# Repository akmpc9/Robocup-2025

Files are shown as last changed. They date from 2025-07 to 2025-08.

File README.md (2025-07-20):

# Robocup-2025

## What is Robocup?
[Robocup Junior Soccer Open](https://junior.robocup.org/soccer/) is a league of the international robotic competition: [RoboCup](https://robocup.org).
For this competition, we need to create _two fully autonomous robots_ that play _soccer_ against other teams. We have to design, build and program the robots without external help. This is a really challenging problem because the robots need to be fully autonomous. They need to detect the ball and try to go towards it to hopefully push it towards the goal. A camera system is needed to try to detect the ball based on its color (it's an orange golf ball) and to detect the opponent's goal.

[Learn more about the competition](https://robocup-junior.github.io/soccer-rules/master/rules.html)

## The robots

## The team
We're a team of 3 high school students from Bordeaux.

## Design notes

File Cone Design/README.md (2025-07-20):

# The cone:
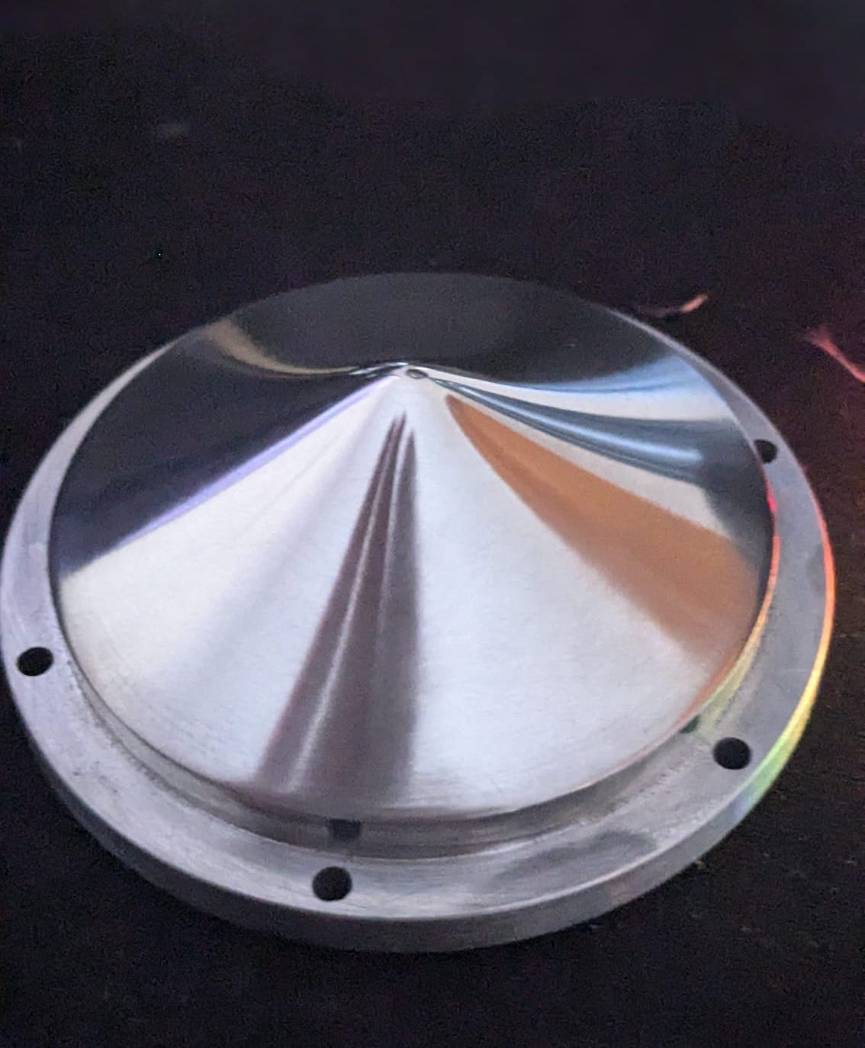
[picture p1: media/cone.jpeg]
Our cone


## What's the cone for?

Robots need to find the ball with the help of a camera. Many robots that simply place cameras in front of their robots need to make them spin until the ball enters the camera's field of vision, and can go towards it. This is a slow strategy. Instead of having the camera placed like this and having to spin slowly, many teams have found alternatives. The main alternatives are:
1. A camera with a fish-eye lens pointing down on the field.
2. Many cameras distributed around the robot.
3. A camera pointed up at a reflective cone.

Most teams go for the third option and so did we. A camera is pointing straight up from the center of the robot. A reflective cone (often cnc machined or created with a reflective film) is placed above it and lets the camera see an image of the field in the reflection. This lets the camera see in 360°.
We had an openmv h7 cam pointed at a cnc-machined aluminum cone.

The camera's view of the field through the cone
*This is the view on the field that the camera gets through our cone. When the cone and camera are well aligned, the cone truly creates a rectangular view of the field.

## Why our cone is interesting
Many teams use hyperbolic mirors to have a view of the field. The cross section of the cone is hyperbolic. We decided to try something different. In the camera's view, using a hyperbolic mirror, the field is very distorted. Seeing this issue, we created a program that creates the perfect cone shape (cross section) for the view of the field to be a rectangle in the image given many inputs such as the camera's position, the cone's position and the field of view. The camera returns an image of the field similar to a photo being taken from far above the field. The value of such an image is that the distance between two points that 15 pixels on the image represents is equivalent to those same 15 pixels somewhere else in the image. We can measure distances in pixels between objects straight off the image, multiply it by a constant and get centimeters. This let us rely solely on the camera to go towards the ball, go towards the goal and avoid going out of bounds.

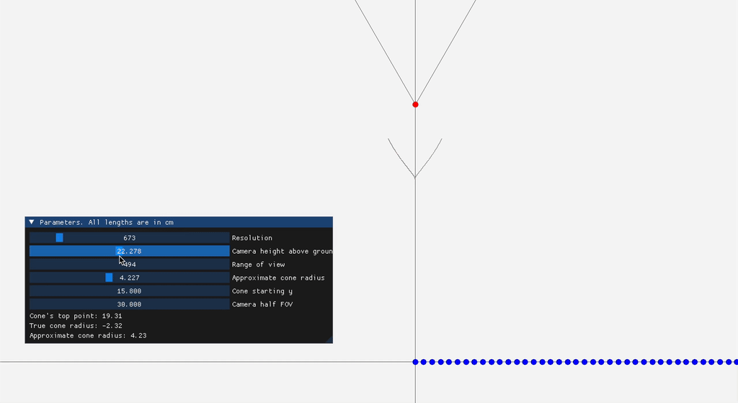
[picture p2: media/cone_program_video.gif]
Cone designing program

*The program has a GUI to let the user create the perfect cone shape based on the parameters. The red point is the camera. the whole image is a cross section of the field. the weirdly shaped line above the camera is the cross section of the cone. It outputs the stl file of the wanted cone when the program shuts.*

## What we would change for the 2026 competition
For next year, we will change many things around the cone:
1. The weight / size. The cone was rather large (6cm in diameter) and therefor raised the center of gravity (making strong accelerations lift a wheel off the ground. This is very negative as it means we lose some control over the robot's movement, and the vision system also breaks down due to measured distances not being valid at all when the robot isn't flat on the ground). Next year, we will create much smaller cones to avoid these issues and to reduce the price of the raw materials.
2. Although the program gave us the shape of the cone we wanted based on our inputted values, it turned out that a range of 1.5m isn't quite enough for the robot (we couldn't see the opponent's goal when we were in our half of the field for example). In other words, the system that gave us the cone worked well, but the values that we gave it will be changed for next year. Another solution to the issue of not seeing the opponent's goal is simply using a lidar (which is the plan for next year's robots) to know exactly where the robot is on the field with the camera only inputting which goal is the closest rather than finding the opponent's goal position.

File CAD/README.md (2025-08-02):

# CAD Models

[Click here to view the full model in Onshape](https://cad.onshape.com/documents/38b8aa48dace08227087a0ba/w/a7972c026289a2e11ccdfcb7/e/f6010eaa08c50660caaa18c2)

---

## 📸 Previews

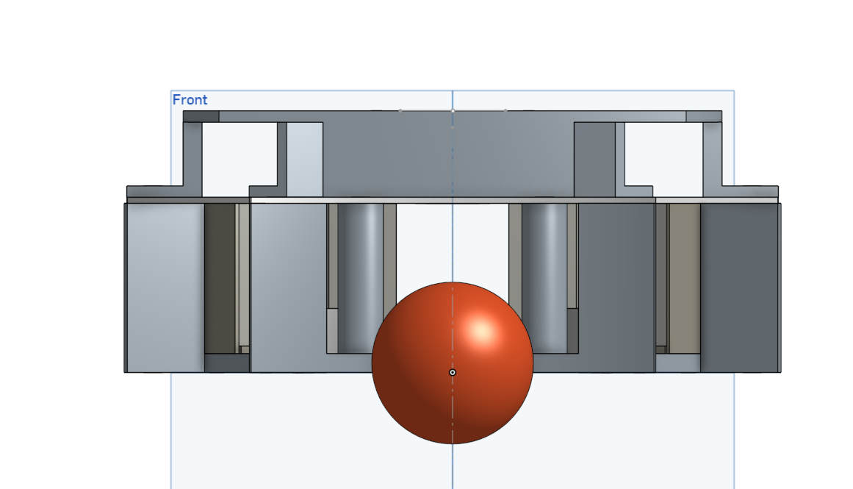
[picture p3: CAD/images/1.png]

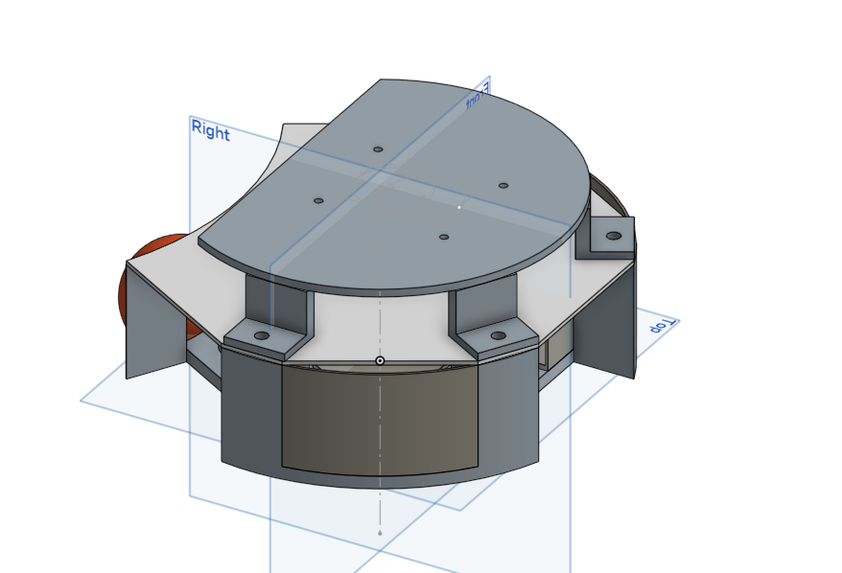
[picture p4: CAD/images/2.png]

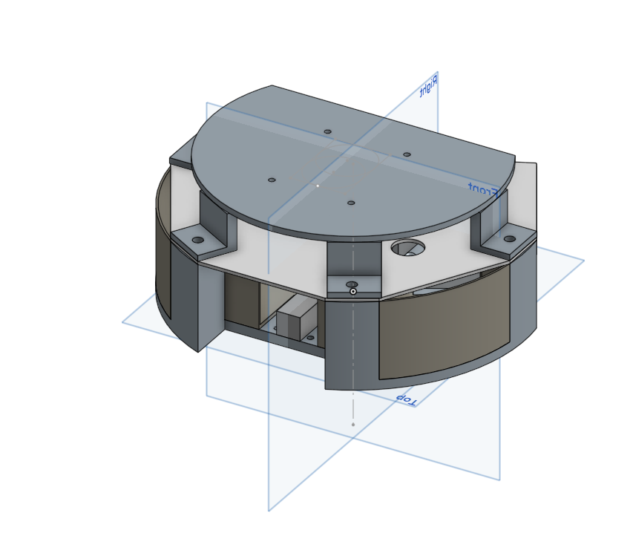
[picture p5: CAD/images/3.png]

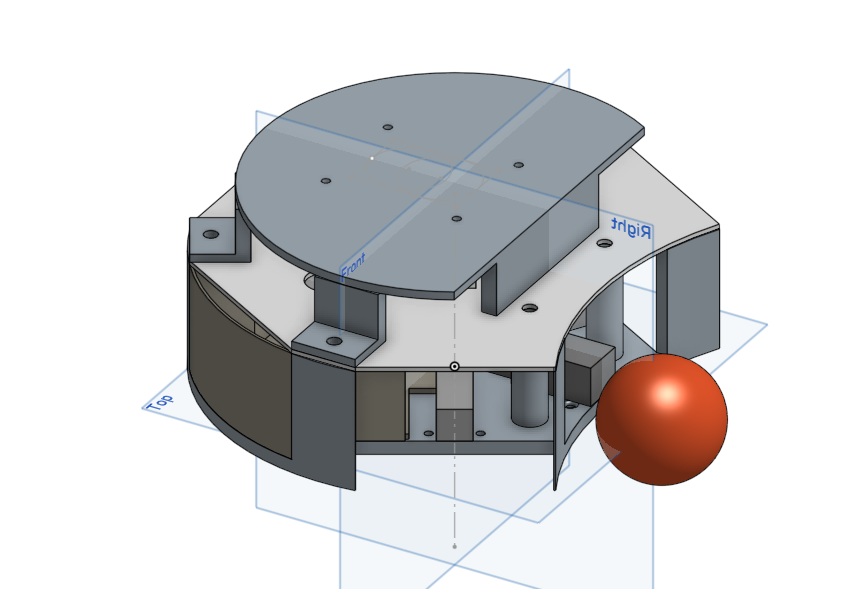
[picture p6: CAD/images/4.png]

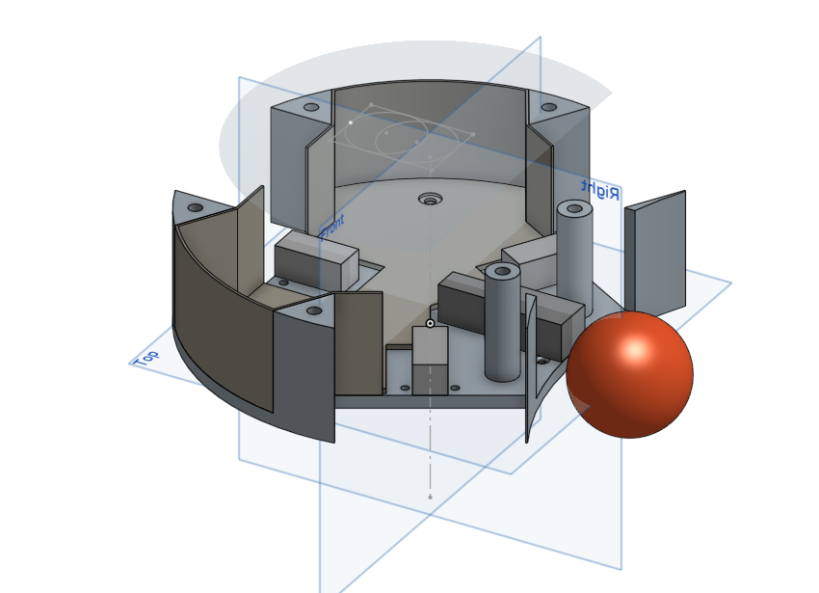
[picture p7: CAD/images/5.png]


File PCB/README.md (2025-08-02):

# Custom PCB Design

This is a 2-layer custom PCB designed in **KiCad 9** and manufactured via **JLCPCB**.

---

## About
  
the **PCB** was created using **KiCad 9**, with a focus on simplicity, and ease of assembly.

---

## Specs

-  **Layers**: 2
-  **EDA Tool**: KiCad 9
-  **Manufacturer**: JLCPCB
-  **Board Dimensions**: _[175mm x 175mm]_
-  **Ground pour for thermal management and EMI reduction.**

---

## 📁 Design Files

The following files are included in this repo:

- `*.kicad_pro` – KiCad 9 project file  
- `*.kicad_pcb` – PCB layout  
- `*.sch` – Schematic  
- `*.pdf` – Schematic2  

---

##  Manufacturing

These files were exported for and tested with **JLCPCB**.

- Designed using [KiCad](https://kicad.org/)
- Manufactured by [JLCPCB](https://jlcpcb.com)

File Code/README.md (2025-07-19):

The Code on our robots worked with two separate components: the esp32 and the camera. The esp32 controlled the robot's movements through the motor controllers while the camera, being the only sensor on board, made of all the stategic decisions. The esp32 was slave to the camera and just recieved simple instructions to move, which it then translated into the individual motor speeds and sent the right instructions to the motor controllers.

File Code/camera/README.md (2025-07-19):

As is rather common with robotics competitions and larger projects, code and other pieces of data aren't often well archived on the spurr of the moment. During competitions, we are often concentrated on getting a version of the code that's working with the current situations rather than saving which versions we used. We therefor can't show one program that represents our robots' code. Many versions have been changed numerous times, and code often changed from one match to the next. In any case, this is the code that has the main components of the code that gave us a goal in six seconds.

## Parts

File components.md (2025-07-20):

# The following are the comoponents we used on the robots for the 2025 competitions
These are the components _per robot_
<span style="color: #FF0000;">This text is red</span>

- Motor controllers:
   - TB6612FNG Motor Driver x2
- Motors:
   - Motoréducteur HPCB 3039, 50:1 (n20 motors) x3
- Wheels:
   - 60mm Omni Wheel Set Plastic x3
- Camera:
   - OpenMV h7 cam x1
- Microcontroller:
   - Esp32 x1
- Materials:
   - PLA for 3d printed parts
   - Aluminum for the cnc machined cone

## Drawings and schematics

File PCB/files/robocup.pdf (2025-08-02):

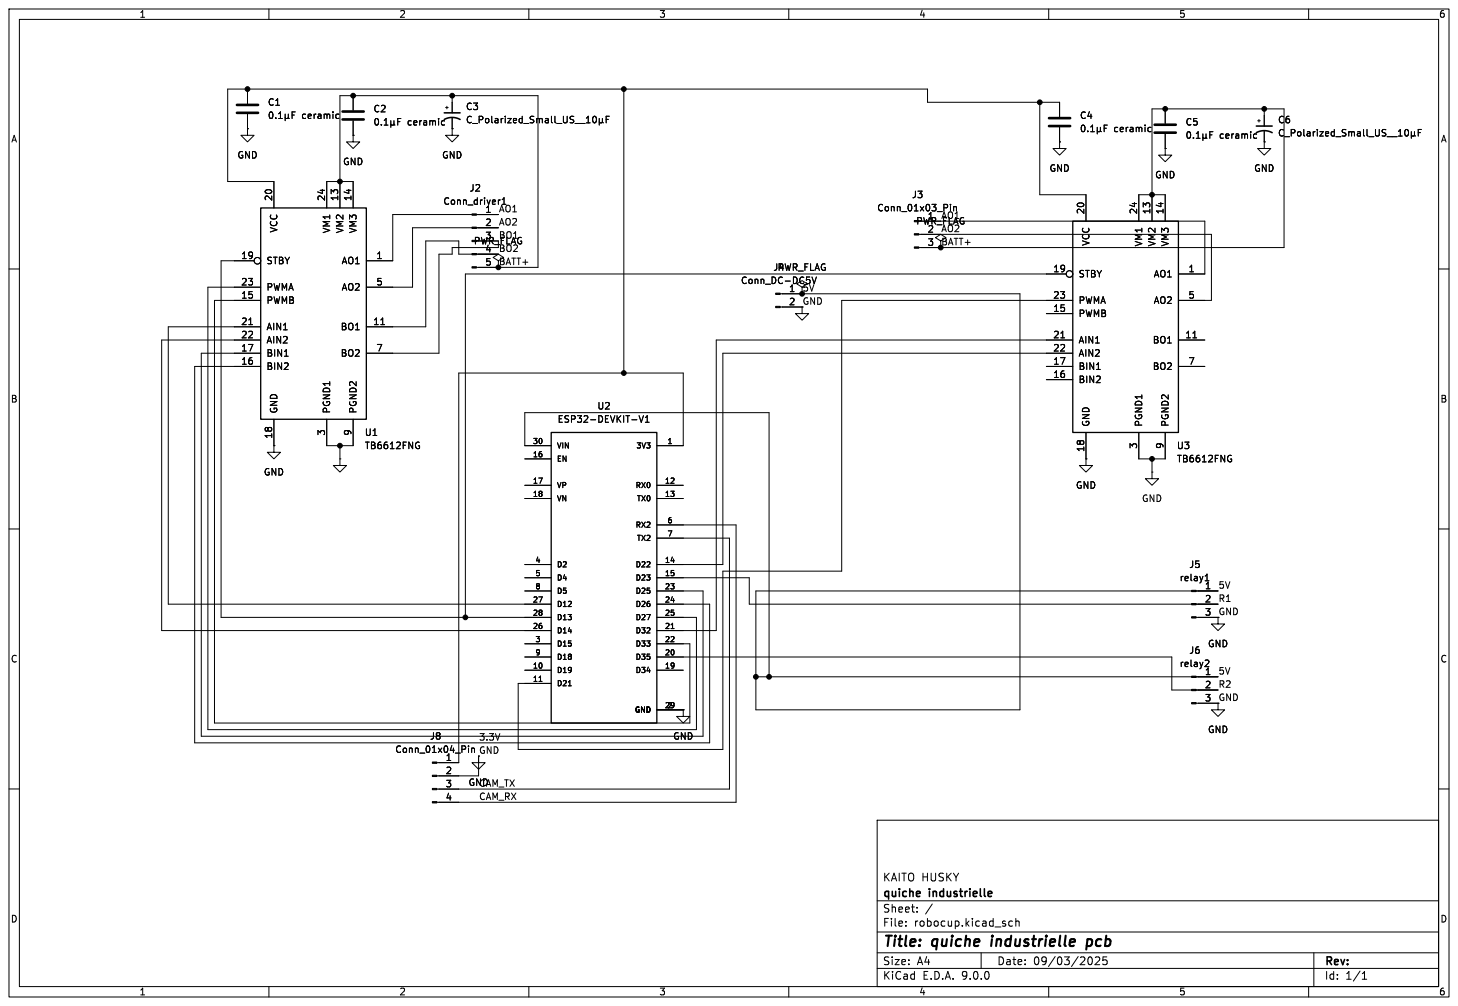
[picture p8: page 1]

File: robocup.kicad_sch Sheet: / quiche industrielle KAITO HUSKY

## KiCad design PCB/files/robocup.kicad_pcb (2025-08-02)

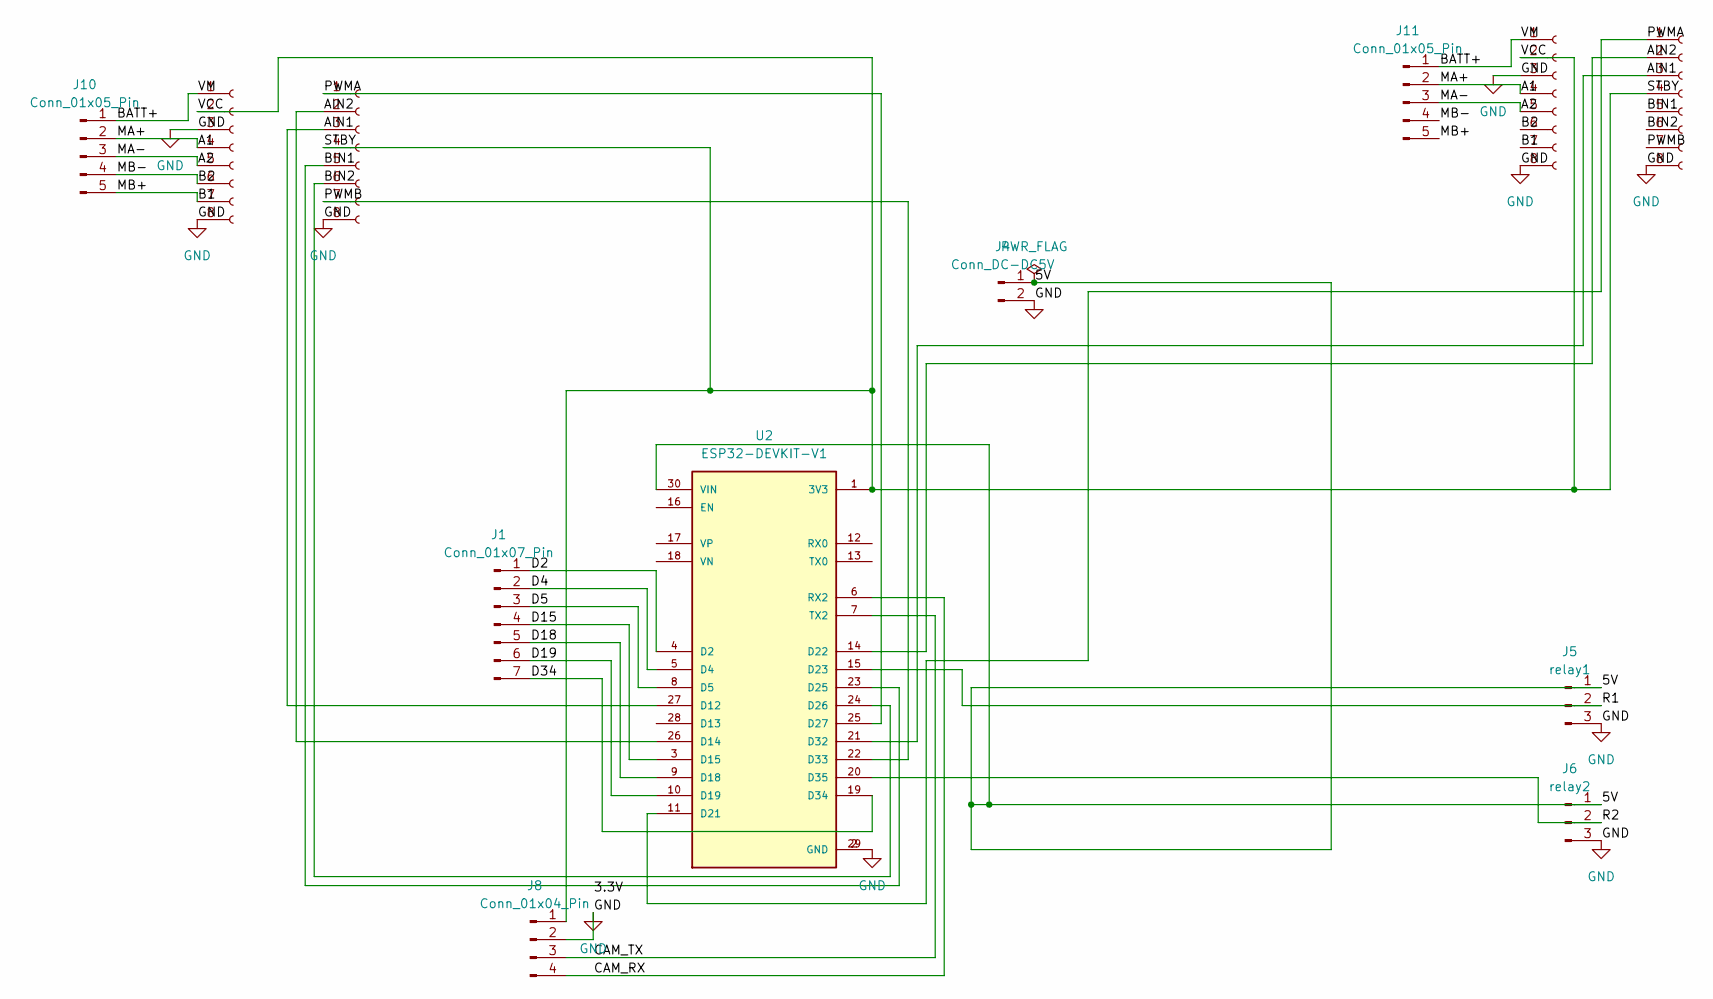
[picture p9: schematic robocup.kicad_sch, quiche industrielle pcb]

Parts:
J1: Conn_01x07_Pin; PinHeader_1x07_P2.54mm_Vertical
J2, J3, J7, J9: Conn_01x08_Socket; PinSocket_1x08_P2.54mm_Vertical
J4: Conn_DC-DC5V; PinHeader_1x02_P2.54mm_Vertical
J5: relay1; PinHeader_1x03_P2.54mm_Vertical
J6: relay2; PinHeader_1x03_P2.54mm_Vertical
J8: Conn_01x04_Pin; PinHeader_1x04_P2.54mm_Vertical
J10, J11: Conn_01x05_Pin; PinHeader_1x05_P2.54mm_Vertical
U2: ESP32-DEVKIT-V1; MODULE_ESP32_DEVKIT_V1; PARTREV N/A

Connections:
/5V: J4.1, J5.1, J6.1, U2.30 (VIN)
/A1: J2.4, J7.4, J10.2, J11.2
/A2: J2.5, J7.5, J10.3, J11.3
/AIN1: J3.3, J9.3, U2.21 (D32), U2.27 (D12)
/AIN2: J3.2, J9.2, U2.14 (D22), U2.26 (D14)
/B1: J2.7, J7.7, J10.5, J11.5
/B2: J2.6, J7.6, J10.4, J11.4
/BATT+: J2.1, J7.1, J10.1, J11.1
/BIN1: J3.5, J9.5, U2.23 (D25)
/BIN2: J3.6, J9.6, U2.24 (D26)
/CAM_RX: J8.4, U2.6 (RX2)
/CAM_TX: J8.3, U2.7 (TX2)
/D2: J1.1, U2.4 (D2)
/D4: J1.2, U2.5 (D4)
/D5: J1.3, U2.8 (D5)
/D15: J1.4, U2.3 (D15)
/D18: J1.5, U2.9 (D18)
/D19: J1.6, U2.10 (D19)
/D34: J1.7, U2.19 (D34)
/PWMA: J3.1, J9.1, U2.11 (D21), U2.25 (D27)
/PWMB: J3.7, J9.7, U2.22 (D33)
/R1: J5.2, U2.15 (D23)
/R2: J6.2, U2.20 (D35)
/STBY: J2.2, J3.4, J7.2, J8.1, J9.4, U2.1 (3V3)
GND: J2.3, J2.8, J3.8, J4.2, J5.3, J6.3, J7.3, J7.8, J8.2, J9.8, U2.2 (GND), U2.29 (GND)

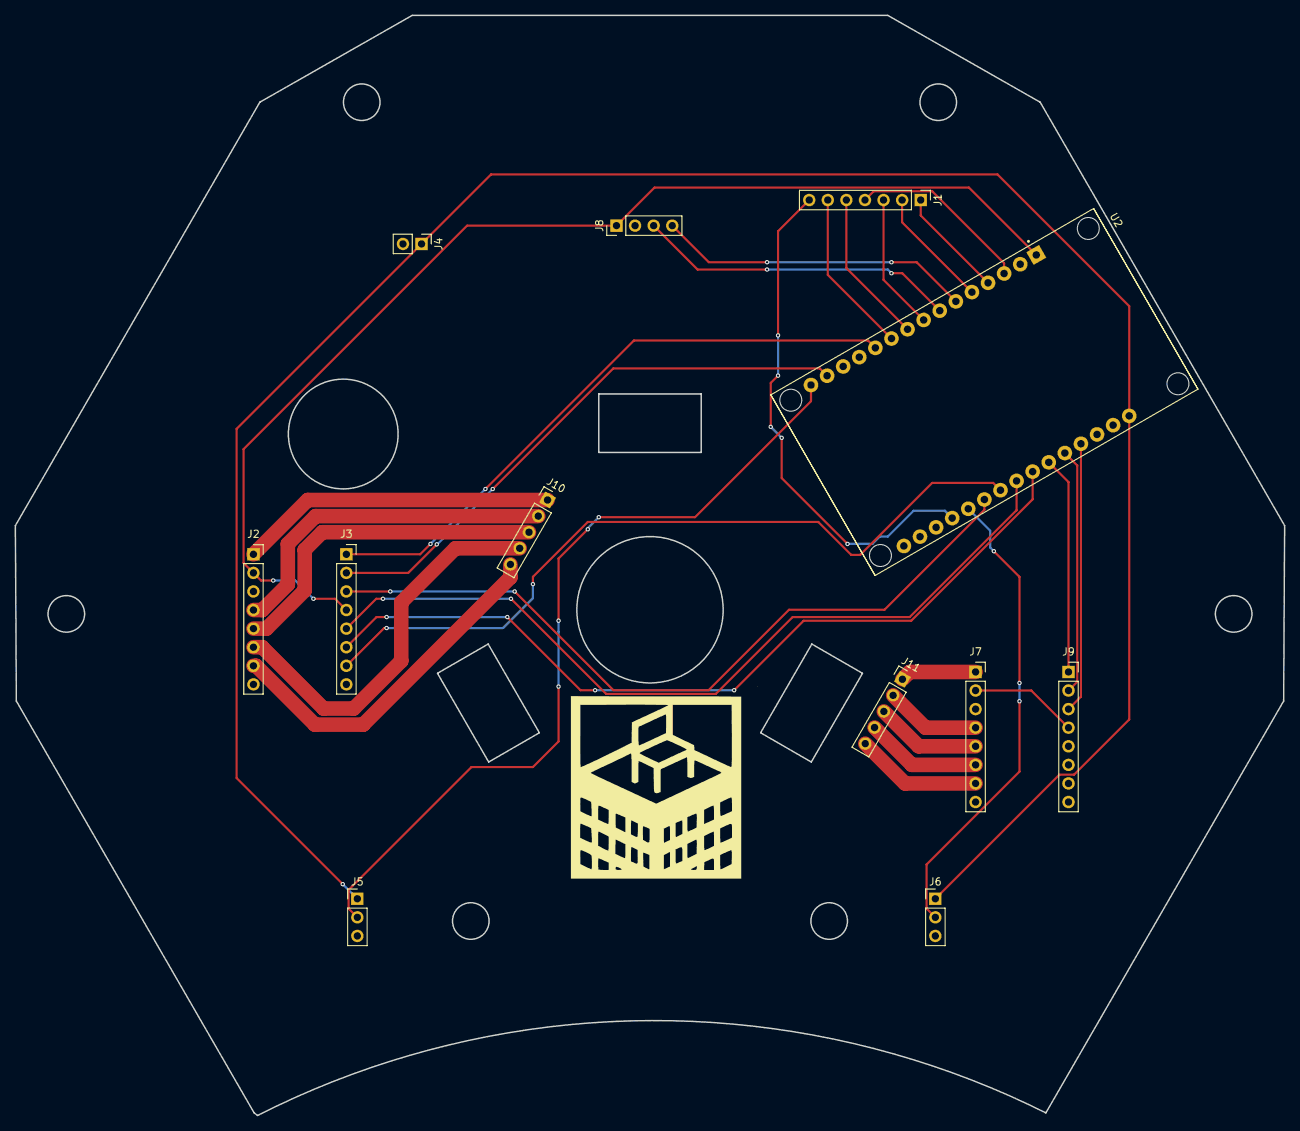
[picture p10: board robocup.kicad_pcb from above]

Board: 2 copper layers, 173.5 x 150.4 mm, 12 parts (0 on the bottom side), 25 nets.

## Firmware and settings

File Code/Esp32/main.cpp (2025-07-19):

#include "driver/mcpwm.h"
#include <HardwareSerial.h>

HardwareSerial camSerial(2);

int PWMB = 25;
int BIN1 = 27;
int BIN2 = 26;

int PWMC = 13;
int CIN1 = 14;
int CIN2 = 12;

int PWMA = 4;
int AIN1 = 15;
int AIN2 = 2;

const float motor_A[2] = {-0.5, 0.866025};
const float motor_B[2] = {-0.5, -0.866025};
const float motor_C[2] = {1, 0};

void setup() {
    Serial.begin(115200);
    mcpwm_gpio_init(MCPWM_UNIT_0, MCPWM0A, PWMA);
    mcpwm_gpio_init(MCPWM_UNIT_0, MCPWM0B, PWMB);
    mcpwm_gpio_init(MCPWM_UNIT_1, MCPWM0A, PWMC);

    mcpwm_config_t pwm_config = {
        .frequency = 5000,
        .cmpr_a = 0,
        .cmpr_b = 0,
        .duty_mode = MCPWM_DUTY_MODE_0,
        .counter_mode = MCPWM_UP_COUNTER
    };

    mcpwm_init(MCPWM_UNIT_0, MCPWM_TIMER_0, &pwm_config);
    mcpwm_init(MCPWM_UNIT_1, MCPWM_TIMER_0, &pwm_config);

    pinMode(AIN1, OUTPUT);
    pinMode(AIN2, OUTPUT);
    pinMode(BIN1, OUTPUT);
    pinMode(BIN2, OUTPUT);
    pinMode(CIN1, OUTPUT);
    pinMode(CIN2, OUTPUT);

    camSerial.begin(115200, SERIAL_8N1, 16, 17);
}

void setMotorA(float speed) {
    if (speed > 0) {
        digitalWrite(AIN1, HIGH);
        digitalWrite(AIN2, LOW);
    } else {
        digitalWrite(AIN1, LOW);
        digitalWrite(AIN2, HIGH);
        speed = -speed;
    }
    mcpwm_set_duty(MCPWM_UNIT_0, MCPWM_TIMER_0, MCPWM_OPR_A, speed);
}

void setMotorB(float speed) {
    if (speed > 0) {
        digitalWrite(BIN1, HIGH);
        digitalWrite(BIN2, LOW);
    } else {
        digitalWrite(BIN1, LOW);
        digitalWrite(BIN2, HIGH);
        speed = -speed;
    }
    mcpwm_set_duty(MCPWM_UNIT_0, MCPWM_TIMER_0, MCPWM_OPR_B, speed);
}

void setMotorC(float speed) {
    if (speed > 0) {
        digitalWrite(CIN1, HIGH);
        digitalWrite(CIN2, LOW);
    } else {
        digitalWrite(CIN1, LOW);
        digitalWrite(CIN2, HIGH);
        speed = -speed;
    }
    mcpwm_set_duty(MCPWM_UNIT_1, MCPWM_TIMER_0, MCPWM_OPR_A, speed);
}

void moveBy(float x, float y, float r = 0) {
    x *= 100;
    y *= -100;
    float powerA = x * motor_A[0] + y * motor_A[1] + r;
    float powerB = x * motor_B[0] + y * motor_B[1] + r;
    float powerC = x * motor_C[0] + y * motor_C[1] + r;
    setMotorA(powerA);
    setMotorB(powerB);
    setMotorC(powerC);
}

void rotateBy(float r) {
    setMotorA(r);
    setMotorB(r);
    setMotorC(r);
}

void loop() {
    if (camSerial.available() || Serial.available() > 0) {
        String cmd;

        if (Serial.available() > 0) {
            cmd = Serial.readStringUntil('\n');
        } else {
            cmd = camSerial.readStringUntil('\n');
        }

        char cmdType = cmd.charAt(0);
        float speed, r, x, y;
        int firstComma, secondComma;

        switch (cmdType) {
            case 'A':
            case 'B':
            case 'C':
                speed = cmd.substring(2).toFloat();
                if (cmdType == 'A') {
                    setMotorA(speed);
                    Serial.printf("set A to %.1f%%\n", speed);
                } else if (cmdType == 'B') {
                    setMotorB(speed);
                    Serial.printf("set B to %.1f%%\n", speed);
                } else {
                    setMotorC(speed);
                    Serial.printf("set C to %.1f%%\n", speed);
                }
                break;

            case 'V':
                firstComma = cmd.indexOf(',');
                secondComma = cmd.indexOf(',', firstComma + 1);
                if (secondComma > 0) {
                    x = cmd.substring(firstComma + 1, secondComma).toFloat();
                    int thirdComma = cmd.indexOf(',', secondComma + 1);
                    if (thirdComma > 0) {
                        y = cmd.substring(secondComma + 1, thirdComma).toFloat();
                        r = cmd.substring(thirdComma + 1).toFloat();
                        moveBy(x, y, r);
                        Serial.printf("moving: x=%.2f, y=%.2f, r=%.2f\n", x, y, r);
                    } else {
                        y = cmd.substring(secondComma + 1).toFloat();
                        moveBy(x, y);
                        Serial.printf("moving: x=%.2f, y=%.2f\n", x, y);
                    }
                }
                break;

            case 'R':
                r = cmd.substring(2).toFloat();
                rotateBy(r);
                Serial.printf("rotating: r=%.2f\n", r);
                break;

            case 'S':
                moveBy(0, 0);
                break;

            default:
                Serial.println("Unknown command");
                break;
        }
    }
}

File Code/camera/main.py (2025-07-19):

import sensor
import time
import math
from pyb import UART
import image


class Vector2:
    def __init__(self, x, y):
        self.x = x
        self.y = y
        self.mag = math.sqrt(self.x*self.x + self.y*self.y)
        if self.mag == 0:
            self.mag = 1

    def normalize(self):
        if self.mag == 0:
            return Vector2(0, 0)
        return Vector2(self.x/self.mag, self.y/self.mag)

    def scale(self, factor):
        return Vector2(self.x*factor, self.y*factor)

    def as_tuple(self):
        return (int(self.x), int(self.y))

    def __add__(self, other):
        return Vector2(self.x + other.x, self.y + other.y)

    def __sub__(self, other):
        return Vector2(self.x - other.x, self.y - other.y)

    def __mul__(self, other):
        return Vector2(self.x * other, self.y * other)

    def __truediv__(self, other):
        return Vector2(self.x / other, self.y / other)

    def __repr__(self):
        return f"Vector2({self.x}, {self.y})"

    def get_angle_degrees(self):
        if self.x == 0 and self.y == 0:
            return 0

        angle = math.atan2(-self.y, -self.x)

        angle_degrees = angle * 180 / math.pi

        return angle_degrees

    def rotate(self, degrees):
        radians = math.radians(degrees)

        old_x = self.x
        old_y = self.y

        new_x = old_x * math.cos(radians) - old_y * math.sin(radians)
        new_y = old_x * math.sin(radians) + old_y * math.cos(radians)

        return Vector2(new_x, new_y)


class Strategy:
    def __init__(self):
        self.state = "search"
        self.last_rotation = None
        # track rotation changes
        self.rotation_history = []
        self.frames_no_ball = 0
        self.frame = 0

    def update(self):
        # ball = get_ball()
        # diff = Vector2(0, 0)
        # if ball:
        #     diff = Vector2(ball.cx(), ball.cy()) - center
        #
        # angle = 0
        # goal = get_color_blob((0, 32, 5, 77, -47, -10))
        # if goal:
        #     angle = goal.cx() - center.x
        #
        # uart.write(f"V,{-diff.x / 100},0,{angle / 10}\n")
        # uart.write("R,40\n")
        # if self.state == "search":
        self.search()
        # elif self.state == "attack":
        # self.attack()
        # elif self.state == "recenter":
        #     self.recenter()
        # else:
        #     uart.write("S\n")

    def stay_in_bounds(self):
        movement = Vector2(0, 0)
        optimal_distance = 33
        for i in range(0, 360, 45):
            diff = raycaster(Vector2(-1, 0).rotate(i), field_threshold)

            if diff.mag < optimal_distance:
                img.draw_circle(*(center + diff).as_tuple(), 3, (255, 0, 0))
                movement += diff * (-diff.mag / (optimal_distance * 60))

        return movement

    def recenter(self):
        East = raycaster(Vector2(0, 1), field_threshold)
        West = raycaster(Vector2(0, -1), field_threshold)

        ball = get_ball()
        if ball:
            self.state = "search"

        angle = 0
        d_y = 164

        if abs(East.mag - West.mag) < 30:
            goal = get_goal()
            if goal:
                diff = Vector2(goal.cx(), goal.cy()) - center
                angle = diff.get_angle_degrees()
                d_y = diff.mag

        uart.write(f"V,{(East.mag - West.mag) /
                   90},{(d_y - 164) / 60},{angle}\n")

    def attack(self):
        ball = get_ball()
        goal = get_goal()
        goal_diff = Vector2(0, 0)

        angle = 0
        if goal:
            goal_diff = Vector2(goal.cx(), goal.cy()) - center
            if goal_diff.mag < 60:
                self.state = "search"
                uart.write("V,0,-0.4,0\n")
                return

        if ball:
            ball_diff = Vector2(ball.cx(), ball.cy()) - center
            angle = ball_diff.get_angle_degrees()
            if ball_diff.mag > 30:
                self.state = "search"

        uart.write(f"V,{-goal_diff.y / 100},{-goal_diff.x /
                   100},{angle + goal_diff.get_angle_degrees() / 3}\n")

        # ball = get_ball()
        # if ball:
        #     if not self.has_ball(ball):
        #         self.state = "search"
        #     # diff = Vector2(ball.cx(), ball.cy()) - center
        #     # if diff.mag > 40:
        #     #     self.state = "search"
        # else:
        #     self.state = "search"
        #
        # diff = self.stay_in_bounds()
        # uart.write(f"V,{diff.x},{diff.y},0\n")

        # goal = get_goal()
        # if goal:
        #     angle = 0
        #     goal_diff = Vector2(goal.cx(), goal.cy()) - center
        #
        #     if goal_diff.mag < 60:
        #         self.state = "search"
        #         uart.write(f"V,{-goal_diff.y / 80},{goal_diff.x / 80},0\n")
        #         return
        #
        #     angle = goal_diff.get_angle_degrees()
        #
        #     diff = Vector2(-70, 0)
        #
        #     ball = get_ball()
        #     if ball:
        #         ball_diff = Vector2(ball.cx(), goal.cy()) - center
        #         ball_diff.y = ball_diff.y * 1.5
        #         if ball_diff.x < 0:
        #             diff = ball_diff + Vector2(-50, 0)
        #         if ball_diff.mag > 30:
        #             self.state = "search"
        #
        #         # ball_angle = ball_diff.get_angle_degrees()
        #         # if abs(ball_diff.get_angle_degrees()) > 30:
        #         #     self.state = "search"
        #
        #         # if ball_angle > 15 or ball_angle < -15:
        #         #     self.state = "search"
        #         self.frames_no_ball = 0
        #     else:
        #         self.frames_no_ball += 1
        #         if self.frames_no_ball > 3:
        #             self.state = "search"
        #
        #     uart.write(f"V,{diff.y / 70},{diff.x / 70},{angle}\n")
        # else:
        #     # uart.write("S\n")
        #     uart.write("V,0,0.4,0\n")
        #     self.state = "search"

    def search(self):
        diff = Vector2(0, 0)
        angle = 0
        goal_diff = None

        goal = get_goal()
        if goal:
            pos = Vector2(goal.cx(), goal.cy())
            goal_diff = pos - center
            # img.draw_circle(*pos.as_tuple(), 5)
            # img.draw_circle(*pos.as_tuple(), 5)
            angle = (Vector2(goal.cx(), goal.cy()) -
                     center).get_angle_degrees()
            if goal_diff.mag < 100:
                uart.write(
                    f"V,{-goal_diff.y / 80},{goal_diff.x / 60},{angle}\n")
                return

        # else:
        #     our_goal = get_color_blob(our_goal_threshold)
        #     if our_goal:
        #         our_goal_diff = Vector2(our_goal.cx(), our_goal.cy()) - center
        #         angle = (our_goal_diff * -1).get_angle_degrees()

        ball = get_ball()
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
